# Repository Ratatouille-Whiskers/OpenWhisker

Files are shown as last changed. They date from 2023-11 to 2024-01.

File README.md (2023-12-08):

# OpenWhisker
 An Open Source Whisker Sensor using a MLX90393

## Navigation

- [Home](README.md)
    - Magnetometer Sensor
      - [Sensor Notes](Code/Sensor%20Notes.md)
      - [Why the ESP32 might be slower than Teensy?](Code/Why%20ESP32%20Might%20be%20slower%20than%20Teensy?.md)
  - CAD
    - [Model Nodes](CAD/Model%20Notes.md)

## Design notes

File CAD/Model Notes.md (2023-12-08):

# Model Notes

General TODO:

- [X] Create a Mould "Platter" For Ratio Testing
- [ ] Create Easy-Edit Parametric Versions for the parts
  - [ ] Whisker Base
  - [ ] Whisker Socket
  - [ ] Whisker Silicone Bearing Mould

## Whisker Base

### [V1](STL/Whisker%20Base/Whisker%20Base%20V1.stl)

- Was too tall (particularly at the bottom) and would need adjusting if wanting to use the mount for breadboard development

### [V2](STL/Whisker%20Base/Whisker%20Base%20V2.stl)

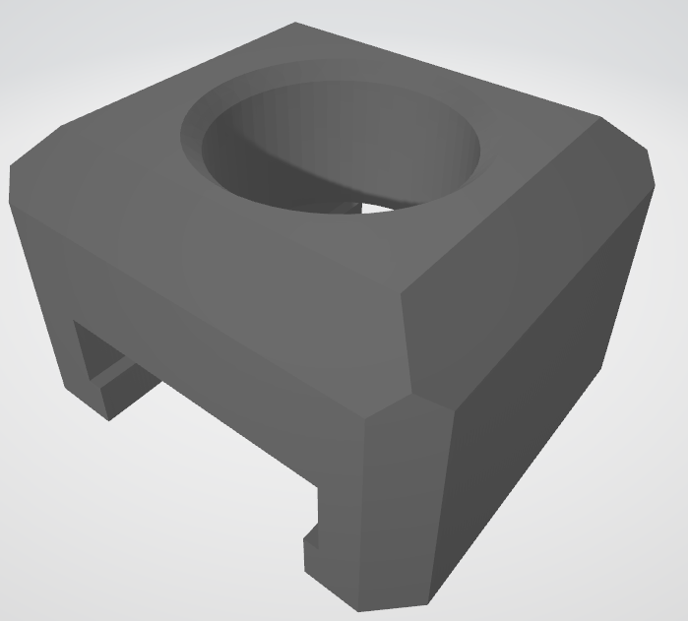
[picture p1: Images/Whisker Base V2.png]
Whisker Base V2 image


- Adjusted the height so the Sensor can more easily socket into a breadboard when assembled

### [V3](STL/Whisker%20Base/Whisker%20Base%20V3.stl)

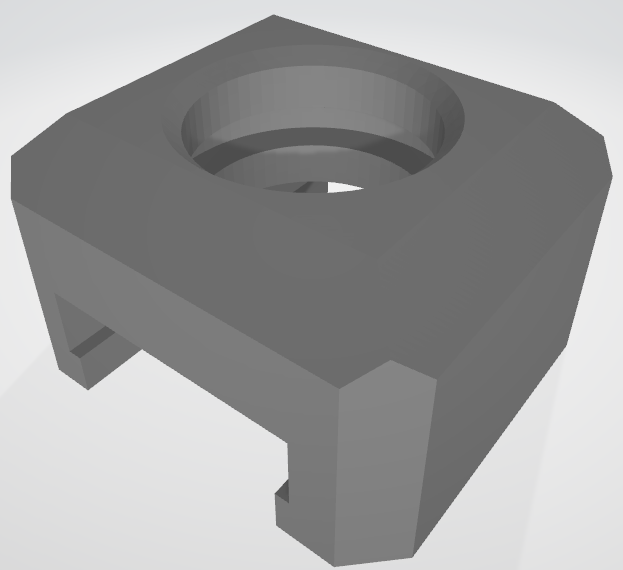
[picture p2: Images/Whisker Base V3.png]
Whisker Base V3 image


- re-centered Silicone Bearing Hole
- added internal cut-out ring in bearing hole so that it can hold better
- Shortened the Height by ~2mm therefore making the bearing space shorter too

### [V4](STL/Whisker%20Base/Whisker%20Base%20V4.stl)

- Made it 4mm taller around the bearing cutout area
- Changed the bearing top chamfer from 1mm to 2mm
- Increased the bearing "outer" ring lip from 3mm tall to 4 mm tall
  - Re-centered this to match the new bearing height

## Whisker Socket

### [V1](STL/Whisker%20Socket/Whisker%20Socket%20V1.stl)

- The socket is designed to a 3mm diameter (printed) whisker
  - The space for the whisker was 4mm to small and would not work
- The socket for inserting a a 5x1 magnet was also too small and need to be wider

### [V2](STL/Whisker%20Socket/Whisker%20Socket%20V2.stl)

- Made it shorter to match the changes to V3 of the base

Top Angle View:

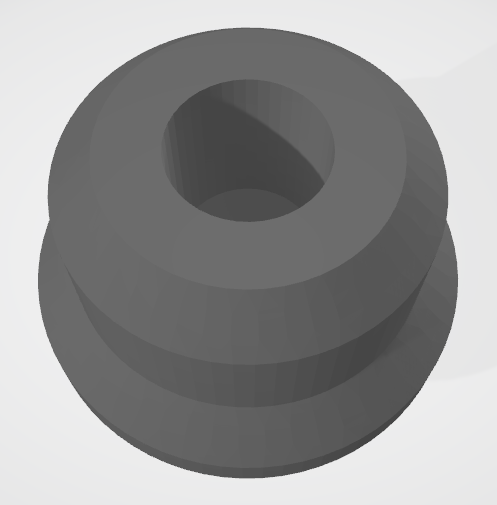
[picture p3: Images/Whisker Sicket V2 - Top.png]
Whisker Socket V2 - Top


Top Angle View:

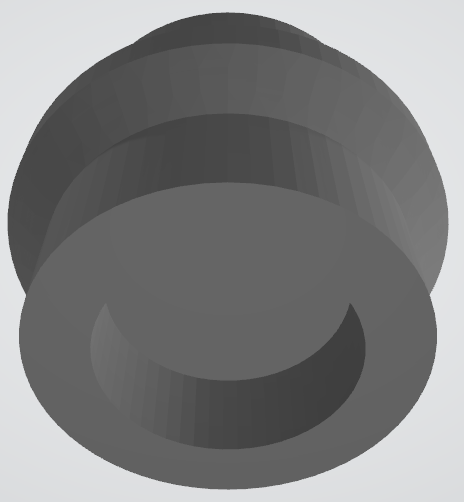
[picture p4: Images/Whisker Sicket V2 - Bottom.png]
Whisker Socket V2 - Bottom


- Increase the sockets by 0.25mm to try and account for print tolerances
  - Done for _Whisker hole_
    - Now hold 3mm diameter rods fine
  - Done for _Magnet hole_
    - Can hold a 5x1 magnet with a drop of super glue

- TODO: _MAYBE_ make it slightly tighter for a press-fit option

#### V2.1

- Made it 1mm shorter on top

### [V3](STL/Whisker%20Socket/Whisker%20Socket%20V3.stl)

- Increase the outer lip rings radius from 5mm to 6mm
  - Re-centered it up the socket
- Increase the height from 9mm to 13mm to better suit V4 of the base
  - Increased the height of the socket "stopper" so that the whisker doesn't sit too far in because of the changes
    - Insertable whisker length has changed from 3mm to 5mm
- Increase the top chamfer from 1mm to 1.5mm
- Changed the Magnet Hole from a radius of 2.65m to 2.6mm for better printer tolerances for press fit for a 5x1mm magnet

### [V3.1](STL/Whisker%20Socket/Whisker%20Socket%20V3_1.stl)

- Corrected Height of the bearing due to error in making it 13mm tall instead of 12mm

### [V4](STL/Whisker%20Socket/Whisker%20Socket%20V4.stl)

This change is done in hope that the bearing and socket hold each other better then the previous versions

- Removed the center ring
- Added a ring lip inline with the bottom of the socket
- added a ring lip near the top

## Casting Jig

### V1

- Create initial Design

### V2

- Removed Small wings as they made it hard to remove the whisker

## Whisker Silicon Bearing Mould

### Single Mould

#### [V1](STL/Whisker%20Silicon%20Bearing%20Mold/Whisker%20Silicon%20Bearing%20Mould%20V1.stl)

Whisker Silicon Bearing Mold V1

- Modified version of V3 to form the mold for the Silicon Bearing to test the various silicones

#### [V2](STL/Whisker%20Silicon%20Bearing%20Mold/Whisker%20Silicon%20Bearing%20Mould%20V2.stl)

- Added the socket to the mold so that bearing is moulded to fit with the socket installed

### 2-Part Mould

#### Top Plate

##### [V1](STL/Whisker%20Silicon%20Bearing%20Mould/2%20Part/Whisker%20Silicon%20Bearing%20Mould%20V1%20-%20Top%20Plate.stl)

- Top plate for pairing with a bottom plate for the bearing mould

##### [V2](STL/Whisker%20Silicon%20Bearing%20Mould/2%20Part/Whisker%20Silicon%20Bearing%20Mould%20V2%20-%20Top%20Plate.stl)

- Made thicker so that the split is better positioned
  
#### Bottom Plate

##### [V1](STL/Whisker%20Silicon%20Bearing%20Mould/2%20Part/Whisker%20Silicon%20Bearing%20Mould%20V1%20-%20Bottom%20Plate.stl)

- Bottom Plate for pairing with a top plate

##### [V2](STL/Whisker%20Silicon%20Bearing%20Mould/2%20Part/Whisker%20Silicon%20Bearing%20Mould%20V2%20-%20Bottom%20Plate.stl)

- Added the socket to the mold so that bearing is moulded to fit with the socket installed

##### [V3](STL/Whisker%20Silicon%20Bearing%20Mould/2%20Part/Whisker%20Silicon%20Bearing%20Mould%20V3%20-%20Bottom%20Plate.stl)

- Made shorter so that the split is better positioned

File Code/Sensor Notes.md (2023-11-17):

# Sensor Notes

## Interesting things found during development

ESP32 AND TEENSY 4.0 HAVE DIFFERENT SPEEDS.

ESP32 IS APRROXIMATELY HALF THE SPEED OF THE TEENSY.
THE `arduino.h` and `wire.h` libraries are different in them.

~~investigate the changes as that could be the reason.~~
The reason is (possibly) due to the differences in how the ESP32 is heavily based around FreeRTOS and therefore has a operating overhead associated with a lot of it's actions. A bit more can be found [here](Why%20ESP32%20Might%20be%20slower%20than%20Teensy?.md)

# #Sample Rate Development Test Results

Setup: 

- Teensy 4.0
- 1K Resistors on both SDA and SCL pins
- Adafruit MLX90393 Breakout Board

`const byte axisFlags = MLX90393::X_FLAG | MLX90393::Y_FLAG | MLX90393::Z_FLAG;`

- Max reading rate is 385hz @ i2c_clk=100kHz
- Max reading rate is 570hz @ i2c_clk=400kHz

`const byte axisFlags = MLX90393::X_FLAG | MLX90393::Y_FLAG;`

- Removing the z-axis from the reading increases 385hz -> 460hz @ i2c_clk=100kHz
- Removing the z-axis from the reading increases 570hz -> 680hz @ i2c_clk=400kHz

`const byte axisFlags = MLX90393::Y_FLAG;`

- Removing the z-axis from the reading increases 460hz -> 578hz @ i2c_clk=100kHz
- Removing the z-axis from the reading increases 680hz -> 870hz @ i2c_clk=400kHz

## MLX90393 (Adafruit Breakout PCB)

- As of 1st May 2023, the i2c address for the sensor has changes from `0x0C` (_12U_) to ` 0x18` (_24_).
- Adafruit Library cap out at ~15Hz Max Sample Rate according to this [issues](https://github.com/adafruit/Adafruit_MLX90393_Library/issues/13)
  - We have found that through a basic setup with the Adafruit Library we can actually reach ~230Hz
    - Using the [MLX90393_Basic_Read](MLX90393_Basic_Read/MLX90393_Basic_Read.ino) with a ESP32 Dev Board connected over i2c
  - The issue above state that **teyapos's** library, [arduino-MLX90393](https://github.com/tedyapo/arduino-MLX90393), could achieve ~500Hz, however we are yet to get this library to work
- The Adafruit PCB include internal Pull-up resistor on board, therefore we don't need to add our own

## Teensy 4.0 (and any other microcontroller used for I2C comms)

- You need to disable the internal Pull-up resistor on the i2c pin as the Sensor PCB include them.
  - **HOWEVER**, we do in fact add 1K resistors to both the SDA and SCL pins as additional pull-up so our signal voltage doesn't drop
    - Ideally these resistors should be ~1.2K

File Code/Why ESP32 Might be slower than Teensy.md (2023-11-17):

# Why ESP32 Might be slower than Teensy?

- difference could be related to FreeRTOS as that is running under the hood for ESP32
  - Doing through the i2c library i find;
    - the timeout, which is set to 50ms, however this is to long for what ime seeing
      - The minimum use of the timeout of the use of Timeout is the ESP is 50ms. The Teensy also set the timeout to 50ms, but they also use it else where with a timeout of 16ms
    - The ESP32 `Wire.h` appears to try and get the a lock before calling `i2cRead()` (line `504` in `Wire.cpp`)
      - **THIS COULD BE THE REASON WHY IT IS SLOWER**

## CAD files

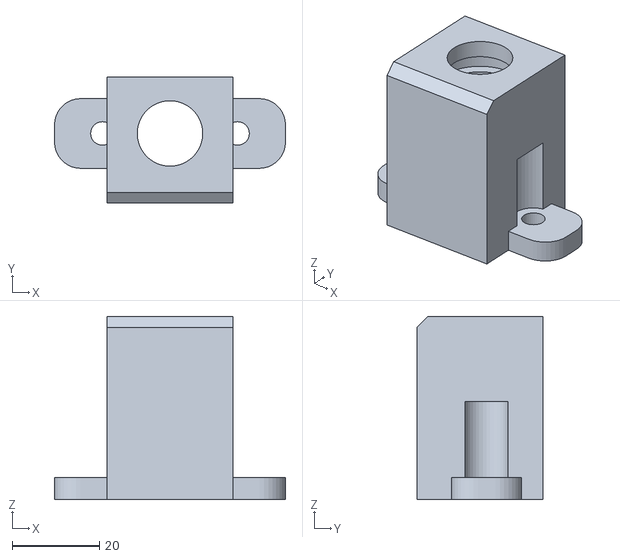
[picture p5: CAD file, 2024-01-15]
CAD/STL/base mutiple sensor mounts V1_1.STL
53.0 x 29.0 x 42.0

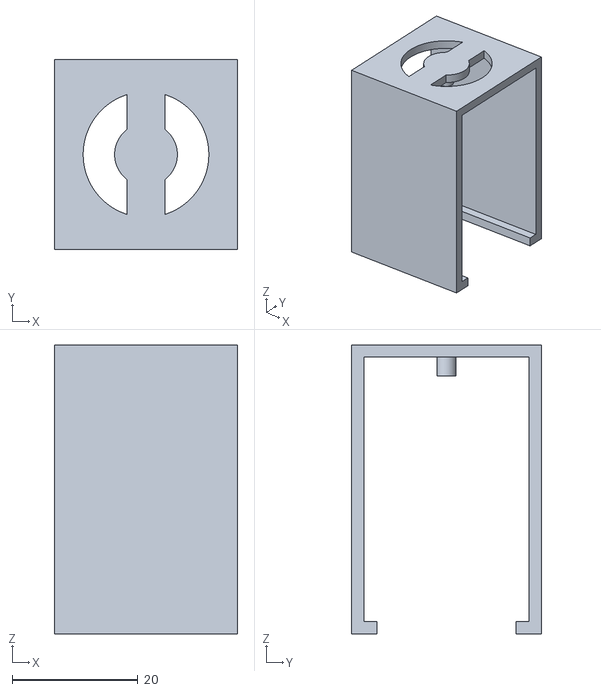
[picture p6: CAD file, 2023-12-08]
CAD/STL/Casting Jig/Casing Jig V2_2.stl
29.2 x 30.2 x 46.0

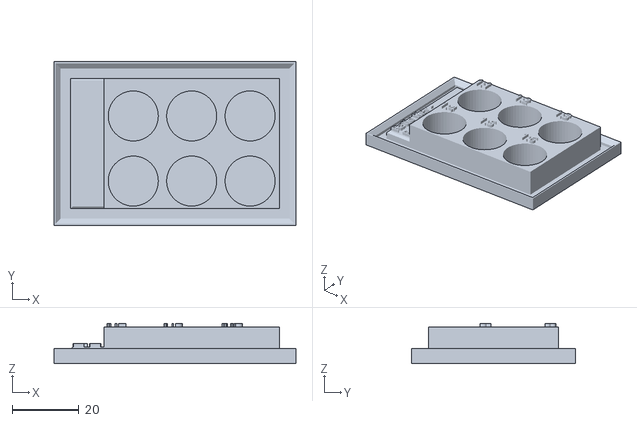
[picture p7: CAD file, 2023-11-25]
CAD/STL/Test Mould Tray/Test Mould Tray V1.stl
72.5 x 49.0 x 12.0

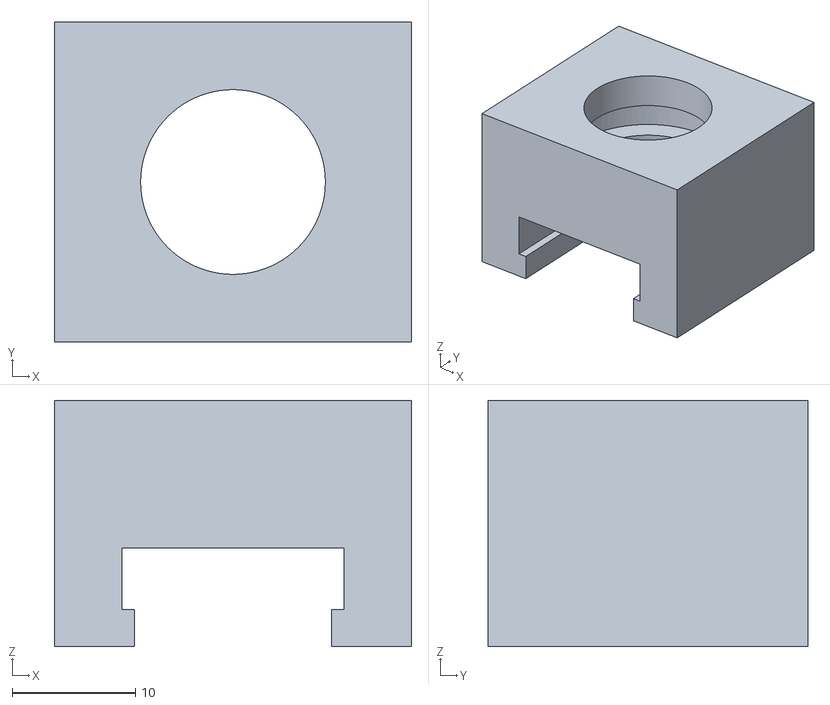
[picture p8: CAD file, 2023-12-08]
CAD/STL/Whisker Base/Whisker Base V4_1.stl
29.0 x 26.0 x 20.0

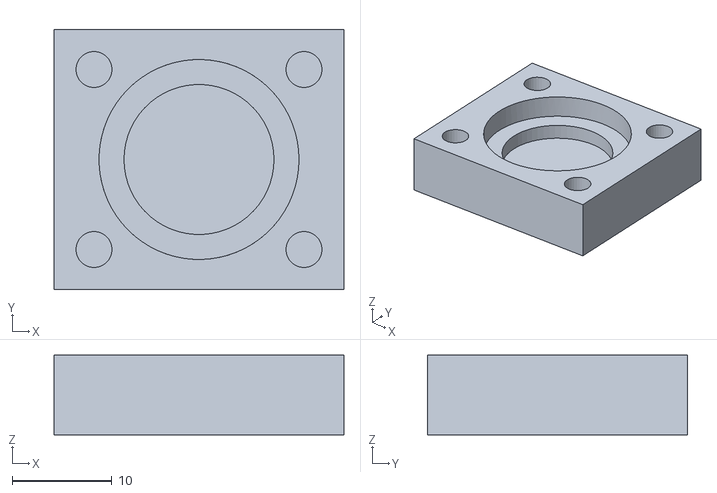
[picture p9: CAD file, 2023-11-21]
CAD/STL/Whisker Silicon Bearing Mould/2 Part/Whisker Silicon Bearing Mould V3 - Bottom Plate.stl
29.0 x 26.0 x 8.00

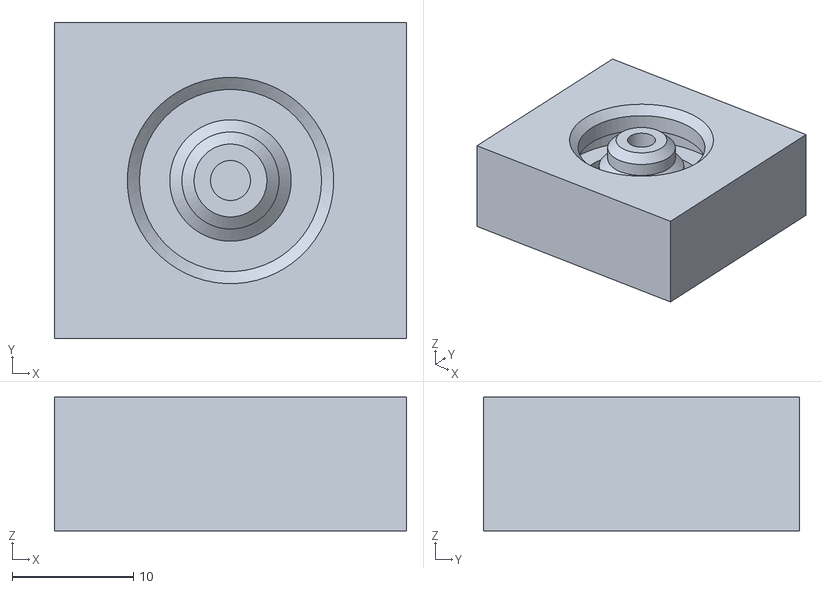
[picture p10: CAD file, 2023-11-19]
CAD/STL/Whisker Silicon Bearing Mould/Whisker Silicon Bearing Mould V2.stl
29.0 x 26.0 x 11.0

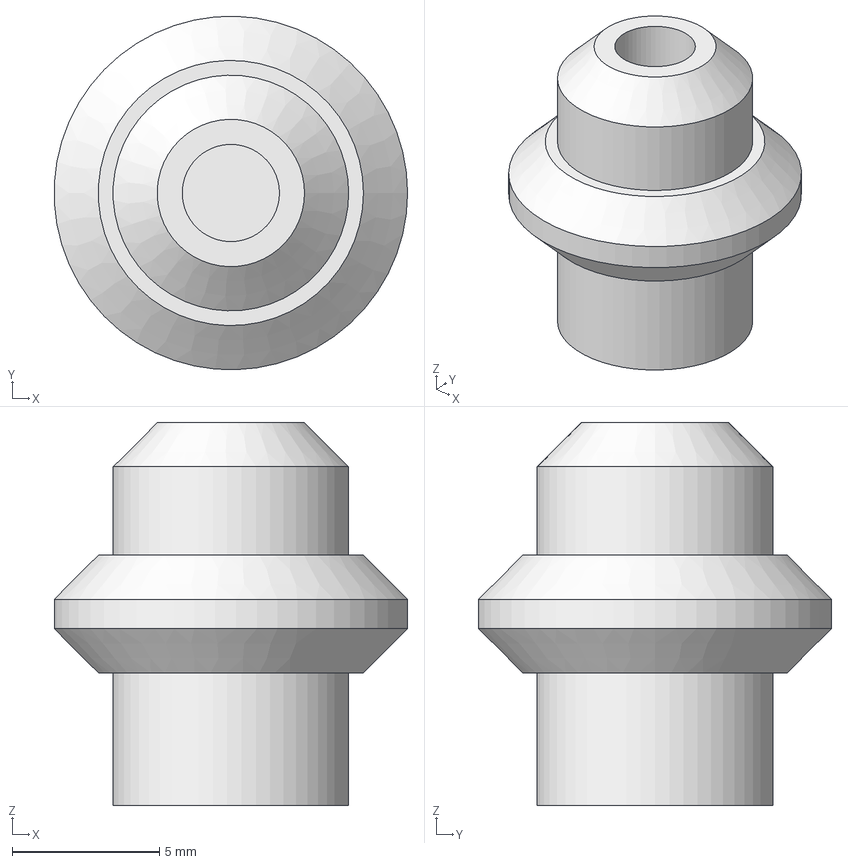
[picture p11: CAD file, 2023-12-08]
CAD/FreeCAD/Whisker Socker.FCStd
12.0 x 12.0 x 13.0 mm

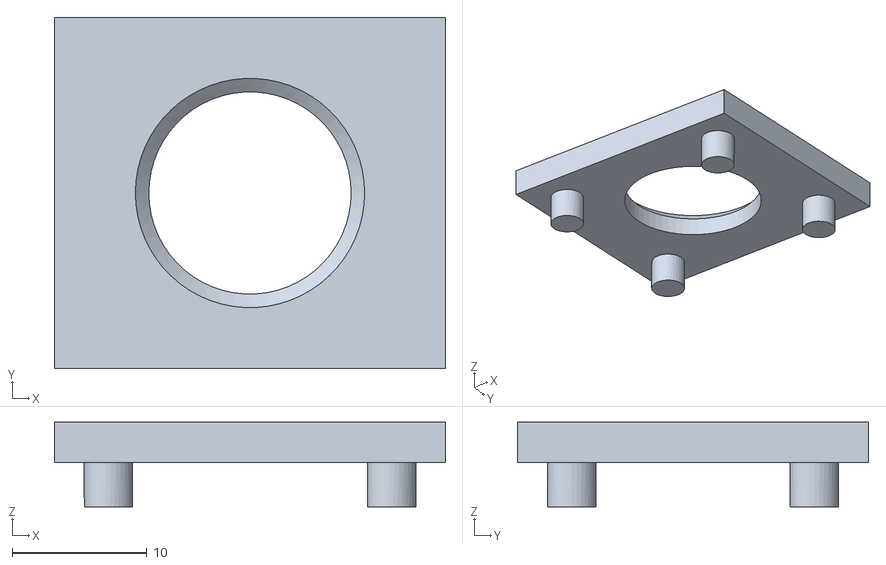
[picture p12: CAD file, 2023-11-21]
CAD/STL/Whisker Silicon Bearing Mould/2 Part/Whisker Silicon Bearing Mould V2 - Top Plate.stl
29.0 x 26.0 x 6.30

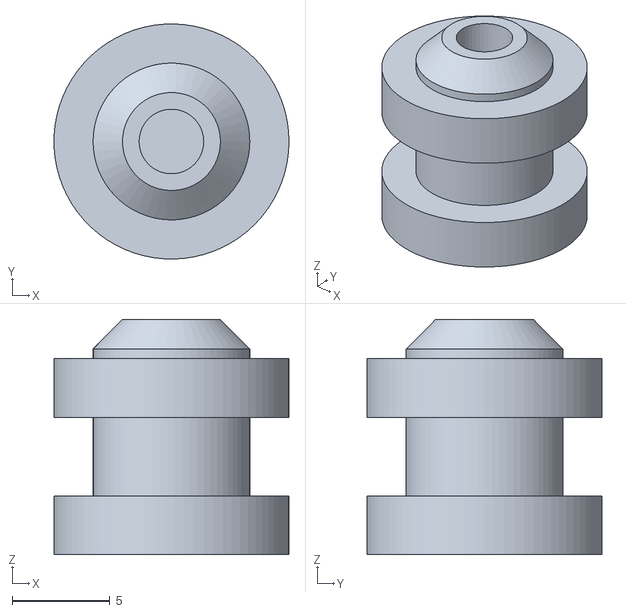
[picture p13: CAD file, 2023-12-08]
CAD/STL/Whisker Socket/Whisker Socket V4_1.stl
12.0 x 12.0 x 12.0

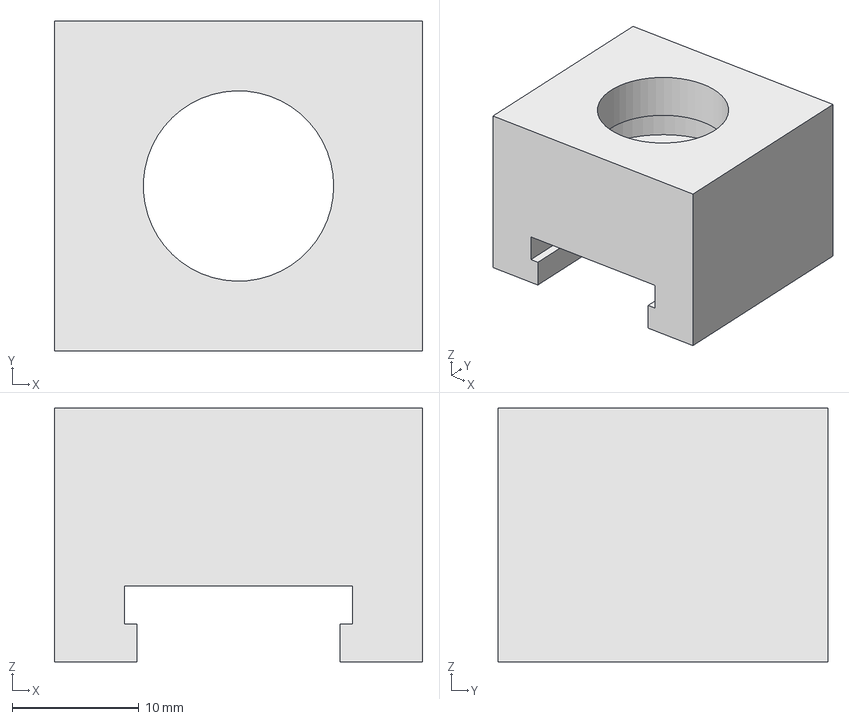
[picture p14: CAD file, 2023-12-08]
CAD/FreeCAD/Whisker base.FCStd
29.0 x 26.0 x 20.0 mm

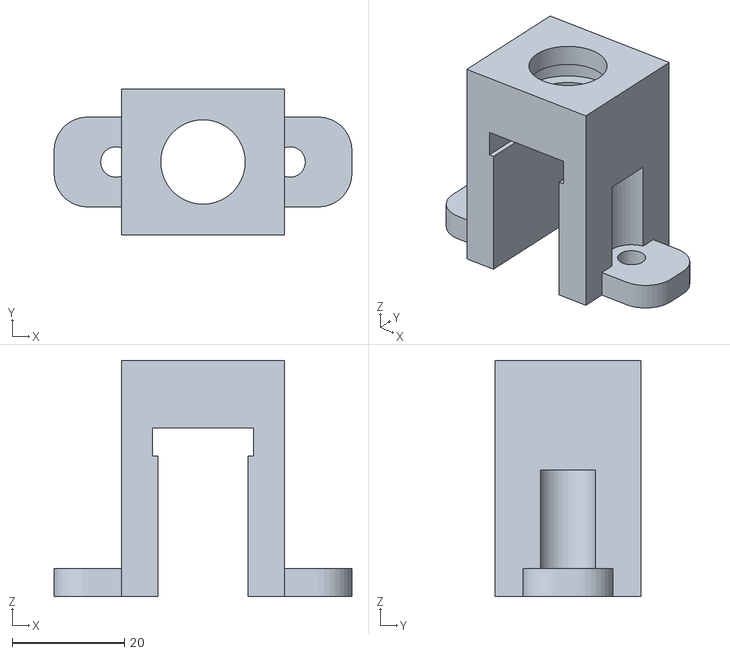
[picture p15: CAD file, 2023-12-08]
CAD/STL/test base final.STL
53.0 x 26.0 x 42.0

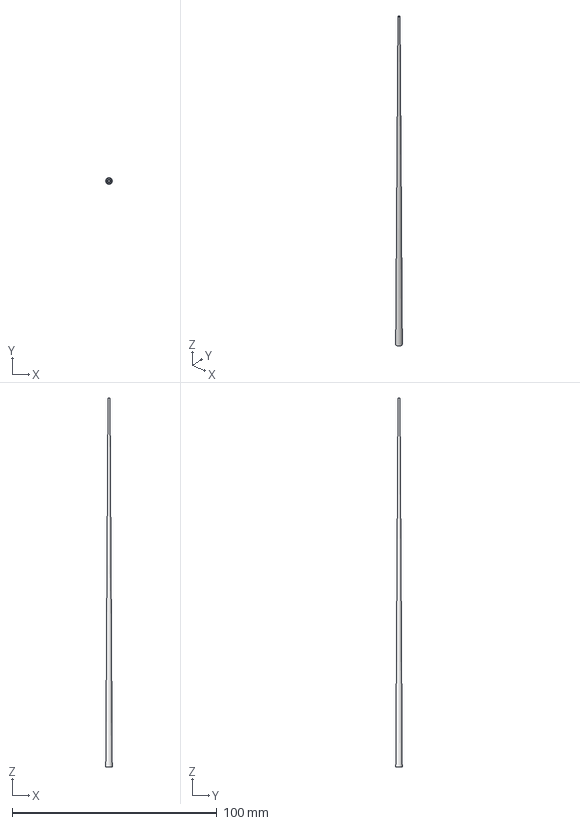
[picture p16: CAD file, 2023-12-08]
CAD/FreeCAD/3,1,180 whicker.FCStd
3.20 x 3.20 x 180.0 mm

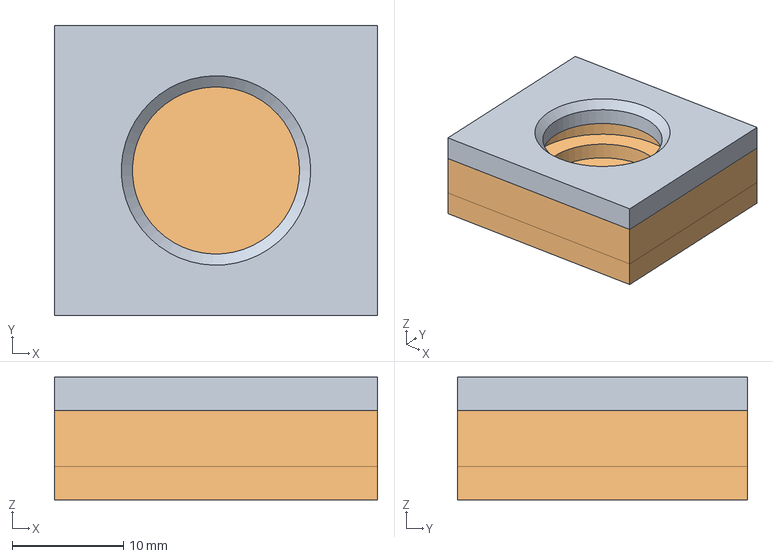
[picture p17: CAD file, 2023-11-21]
CAD/FreeCAD/Whisker Silicon Bearing Mould - 2 Part.FCStd
29.0 x 26.0 x 11.0 mm
Top Plate
Bottom Plate

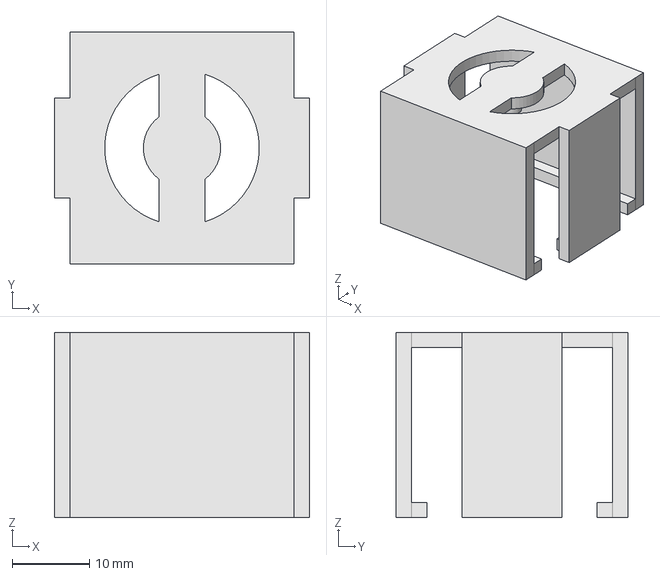
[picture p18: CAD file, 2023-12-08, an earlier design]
CAD/FreeCAD/Casing Jig V1.FCStd
33.0 x 30.0 x 24.0 mm

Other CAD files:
CAD/FreeCAD/Casing Jig V2.FCStd
CAD/FreeCAD/Whisker Socket - V4+.FCStd
CAD/FreeCAD/Test Mould Tray.FCStd
CAD/FreeCAD/Whisker Silicon Bearing Mould.FCStd
CAD/STL/Casting Jig/Casing Jig V1.stl
CAD/STL/Casting Jig/Casing Jig V2.stl
CAD/STL/Casting Jig/Casing Jig V2_1.stl
CAD/STL/Whisker Base/Whisker Base V1.stl
CAD/STL/Whisker Base/Whisker Base V2.stl
CAD/STL/Whisker Base/Whisker Base V3.stl
CAD/STL/Whisker Base/Whisker Base V4.stl
CAD/STL/Whisker Silicon Bearing Mould/2 Part/Whisker Silicon Bearing Mould V1 - Bottom Plate.stl
CAD/STL/Whisker Silicon Bearing Mould/2 Part/Whisker Silicon Bearing Mould V1 - Top Plate.stl
CAD/STL/Whisker Silicon Bearing Mould/2 Part/Whisker Silicon Bearing Mould V2 - Bottom Plate.stl
CAD/STL/Whisker Silicon Bearing Mould/Whisker Silicon Bearing Mould V1.stl
CAD/STL/Whisker Socket/Whisker Socket V1.stl
CAD/STL/Whisker Socket/Whisker Socket V2.stl
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

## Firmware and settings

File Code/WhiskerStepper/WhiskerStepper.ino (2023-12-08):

// Bounce.pde
// -*- mode: C++ -*-
//
// Make a single stepper bounce from one limit to another
//
// Copyright (C) 2012 Mike McCauley
// $Id: Random.pde,v 1.1 2011/01/05 01:51:01 mikem Exp mikem $

#include <AccelStepper.h>

#define Stepper1StepPin 27
#define Stepper1DirPin 26

// Define a stepper and the pins it will use
// AccelStepper stepper; // Defaults to AccelStepper::FULL4WIRE (4 pins) on 2, 3, 4, 5

AccelStepper stepper (AccelStepper::DRIVER, Stepper1StepPin, Stepper1DirPin);

long dx = 0;

void setup()
{  
  // Change these to suit your stepper if you want
  stepper.setMaxSpeed(6000);
  stepper.setAcceleration(4000);
  // stepper.moveTo(6400);

  // 1mm per 200 pulses at 1/4-step
}

void loop()
{

    // If at the end of travel go to the other end
    if (stepper.distanceToGo() == 0){
      if(stepper.currentPosition() > 10){
        stepper.moveTo(0);
      }
      else{
        stepper.moveTo(dx+=200);
        // dx += 200;
        dx %= 4000;
      }
      delay(2000);
    }

    stepper.run();
}

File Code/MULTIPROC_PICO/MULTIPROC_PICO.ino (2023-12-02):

#include <MLX90393.h>
#include <math.h>

#define HIGH_PRIORITY 1
#define DRDY_pin 21
#define DEBUG_pin 18

MLX90393 mlx;
MLX90393::txyzRaw rawData;
MLX90393::txyzRaw rawData_offset;
MLX90393::txyz data;

const uint axisFlags = MLX90393::X_FLAG | MLX90393::Y_FLAG;
// const uint axisFlags = MLX90393::X_FLAG | MLX90393::Y_FLAG | MLX90393::Z_FLAG;

volatile bool dataReady = false;
volatile bool procReady = false;

void loop1()
{
    int reads = 0;
    unsigned long duration = micros();
    unsigned long prev_time = micros();

    while (1)
    {
        if (procReady)
        {
          procReady = false;

          // reads++;
          // if (reads > 1000)
          // {
          //     duration = micros() - prev_time;
          //     Serial.print(duration);
          //     Serial.print(" ");
          //     Serial.print(reads);
          //     Serial.print(" | ");
          //     Serial.print("READ FREQ:");
          //     Serial.println(1000000.0 / (float(duration) / reads));

          //     for (int i = 0; i < 30; i++){delay(100);}

          //     reads = 0;
          //     prev_time = micros();
          // }

          // gpio_put(DEBUG_pin, 1);
          Serial.printf(">X: %f\r\n", data.x);
          Serial.printf(">Y: %f\r\n", data.y);
          // Serial.printf(">Z: %f\r\n", data.z);
          // Serial.printf(">X: %u\r\n", rawData.x - rawData_offset.x);
          // Serial.printf(">Y: %u\r\n", rawData.y - rawData_offset.y);
          // Serial.printf(">Z: %u\r\n", rawData.z - rawData_offset.z);
          // gpio_put(DEBUG_pin, 0);
        }
    }
}

void mlxInterrupt() {
    dataReady = true;
}

void setup() {
    Serial.begin(115200);
    // Serial.begin(921600);

    while (!Serial)
    {
        delay(10);
    }

    attachInterrupt(DRDY_pin , mlxInterrupt, RISING);

    pinMode(DRDY_pin, INPUT_PULLDOWN);
    pinMode(DEBUG_pin, OUTPUT);

    Wire.setSDA(16); 
    Wire.setSCL(17);
    Wire.setClock(400000);
    Wire.begin();

    // byte status = mlx.begin(0, 0, DRDY_pin, Wire); // OLD INIT
    byte status = mlx.begin(0x18, DRDY_pin, Wire);

    mlx.setGainSel(0);
    mlx.setOverSampling(0);
    mlx.setDigitalFiltering(0);
    mlx.setResolution(1, 1, 1);
    mlx.setTemperatureCompensation(0);

    delay(100);

    // Serial.printf("Measurement Starting\n");
    mlx.startBurst(axisFlags);
    
    delay(500);

    // Auto-Zero?
    // NON ROLLING AVG
    // TODO: ROLLING AVG?
    uint16_t i=0;
    while(i<1000){
      if(dataReady){
        dataReady = false;
        mlx.readMeasurement(
          axisFlags,
          rawData
        );

        if(i==0){
          rawData_offset.x = rawData.x;
          rawData_offset.y = rawData.y;
          rawData_offset.z = rawData.z;
        }

        rawData_offset.x = (rawData_offset.x >> 1) + (rawData.x >> 1);
        rawData_offset.y = (rawData_offset.y >> 1) + (rawData.y >> 1);
        rawData_offset.z = (rawData_offset.z >> 1) + (rawData.z >> 1);

        i++;
        // Serial.printf("I: %u\r\n", i);

      }
    }

    // TEMP COMP OFFSET
    // rawData_offset.x -= (uint16_t) 0x8000;
    // rawData_offset.y -= (uint16_t) 0x8000;
    // rawData_offset.z -= (uint16_t) 0x8000;

    // Serial.printf("offset_X: %u\r\n", rawData_offset.x);
    // Serial.printf("offset_Y: %u\r\n", rawData_offset.y);
    // Serial.printf("offset_Z: %u\r\n", rawData_offset.z);

    // delay(15000);

}

void loop(){
  if(dataReady){
    dataReady = false;
    mlx.readMeasurement(
      axisFlags,
      rawData
    );

    rawData.x -= rawData_offset.x;
    rawData.y -= rawData_offset.y;
    // rawData.z -= rawData_offset.z;

    data = mlx.convertRaw(rawData);
    procReady = true;
  }
}

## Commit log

2023-10-24 Created Sensor Notes
2023-10-25 Updated Sensor Notes
2023-10-25 Planning to implement interrupt read code
2023-10-25 Interrupt sampling @ ~360Hz
2023-10-26 570Hz on a Teensy 4.0!!
2023-10-28 Create Why ESP32 Might be slower than Teensy?.md
2023-10-28 Updated Interrupt Example so that i runs the i2c at tit's fastest + with some test data
2023-10-28 Update Sensor Notes.md
2023-11-17 Added (Rough) CAD Prototypes for Silicon Type
    [Whisker Base V2.stl, Whisker Base.stl, Whisker Sensor Socket V2.stl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]
2023-11-17 Rename Why ESP32 Might be slower than Teensy?.md to Why ESP32 Might be slower than Teensy.md
2023-11-17 Corrected CAD File Naming
    [Whisker Base V2.stl, Whisker Base.stl, Whisker Sensor Socket V2.stl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]
2023-11-17 Updated Whisker base and fixed V2
    [Whisker Base V2.stl, Whisker base.FCStd]
2023-11-19 Whisker Base V3 + Notes Update
    [Whisker Base V3.stl]
2023-11-19 Updated Model Notes and files for better tracking
    [Whisker Base V1.stl, Whisker Socket V1.stl]
2023-11-19 Updated V3
    [Whisker Base V3.stl, Whisker base.FCStd]
2023-11-19 Version 1 of Silicone Mould
    [Whisker Silicon Bearing Mold V1.stl, Whisker Silicon Bearing Mold.FCStd]
2023-11-19 Silicon Mould Design Iterations
    [Whisker Silicon Bearing Mold.FCStd, Whisker Silicon Bearing Mould V1.stl, Whisker Silicon Bearing Mould V2.stl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]
2023-11-19 2 Part Mould Version
    [Whisker Silicon Bearing Mould V1 - Bottom Plate.stl, Whisker Silicon Bearing Mould V1 - Top Plate.stl, Whisker Silicon Bearing Mould V2 - Bottom Plate.stl]
2023-11-19 V2.1 Socket Revision
    [Whisker Socker.FCStd, Whisker Socket V2_1.stl]
2023-11-21 Updated 2 Part Mould for a better placed Split
    [Whisker Silicon Bearing Mould - 2 Part.FCStd, Whisker Silicon Bearing Mould V2 - Top Plate.stl, Whisker Silicon Bearing Mould V3 - Bottom Plate.stl]
2023-11-21 Add speedy pico implementation.
2023-11-25 Silicon Test Tray V1
    [Test Mould Tray V1.stl, Test Mould Tray.FCStd]
2023-12-02 Updated Whisker Socket to V3
    [Whisker Socker.FCStd, Whisker Socket V3.stl]
2023-12-02 Updated Whisker Base to V4
    [Whisker Base V4.stl, Whisker base.FCStd]
2023-12-02 Updated CAD Model Changes for the base and socket
2023-12-02 Add new I2C addressing. Add zeroing.
2023-12-02 Remove print statement. Add parser script.
2023-12-02 V1 Draft for Bearing Casting Jig
    [Casing Jig.FCStd, Whisker Socker.FCStd, Whisker base.FCStd]
2023-12-02 Create Casing Jig V1.stl
    [Casing Jig V1.stl]
2023-12-02 Renamed Jig Freecad File
    [Casing Jig V1.FCStd, Casing Jig.FCStd]
2023-12-02 Create Whisker Socket V3_1.stl
    [Whisker Socket V3_1.stl]
2023-12-02 Update Casing Jig V1.FCStd
    [Casing Jig V1.FCStd]
2023-12-03 Updated Casting Jig to V2
    [Casing Jig V2.FCStd, Casing Jig V2.stl]
2023-12-03 Updated Model notes for Socket V3 and Jig V2
2023-12-04 Created V4 of the Whisker Socket
    [Whisker Socket - V4+.FCStd, Whisker Socket V4.stl]
2023-12-06 V4_1 of the socket (probably not needed though)
    [Whisker Socket - V4+.FCStd, Whisker Socket V4_1.stl]
2023-12-06 V4_1 of Whisker Base -Recentered Sensor cutout
    [Whisker Base V4_1.stl, Whisker base.FCStd]
2023-12-06 Casting Jig V2_1
    [Casing Jig V2.FCStd, Casing Jig V2_1.stl]
2023-12-06 Update Casing Jig V2_1.stl
    [Casing Jig V2_1.stl]
2023-12-06 Update Casing Jig V2.FCStd
    Made changes for V2.1
    [Casing Jig V2.FCStd]
2023-12-06 Updated Whisker Base Freecad file to be Spreadsheet Editable
    [Whisker base.FCStd]
2023-12-06 Moved FreeCAD file into there own folder
    [3,1,180 whicker.FCStd, Casing Jig V1.FCStd, Casing Jig V2.FCStd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]
2023-12-06 Updated Casting Jig to V2_2 with better tolerances
    [Casing Jig V2.FCStd, Casing Jig V2_2.stl]
2023-12-06 Corrected Errors in Casting Jig V2_2
    [Casing Jig V2.FCStd, Casing Jig V2_2.stl]
2023-12-08 Add stepper code. Edit hardwired serial port. Add preliminary data.
2024-01-12 Excel sheet updated with magnetometer vs deflection. Minor progress in the mathematical model
2024-01-15 Updated base mutiple sensor mounts V1_1.STL
    [base mutiple sensor mounts V1_1.STL]
